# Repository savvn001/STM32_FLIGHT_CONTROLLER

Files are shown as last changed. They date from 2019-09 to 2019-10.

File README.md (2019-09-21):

# STM32_FLIGHT_CONTROLLER

(Still undergoing active development)

Open source flight controller running on an STM32F411RE MCU and a custom designed PCB. Project written in STM32cubeIDE. 

The other modules this flight controller currently uses:

- NRF24L01PA for RF comms
- GPS is provided by a uBlox NEO6M GPS module
- Orientation from an MPU9250 9-axis IMU.

Current features:
- User control
- Packetised RF communications
- GPS 
- In flight monitoring of telemetry information (battery level, orientation, GPS co-ordinates etc.)
- More to come!

The first revision of the flight controller designed in eagle is shown below.

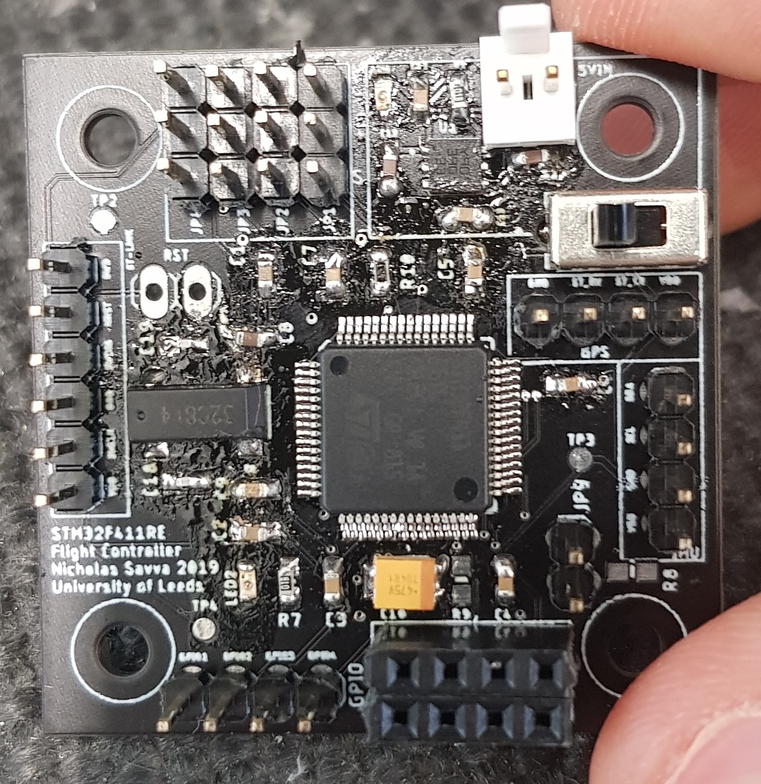
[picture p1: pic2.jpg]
Flight controller PCB


The controller features headers for I2C, 4 GPIO pins, UART and an NRF24L01 module. The code for the associated user controller/transmitter is here: https://github.com/savvn001/DRONE_CONTROLLER_F4746NG

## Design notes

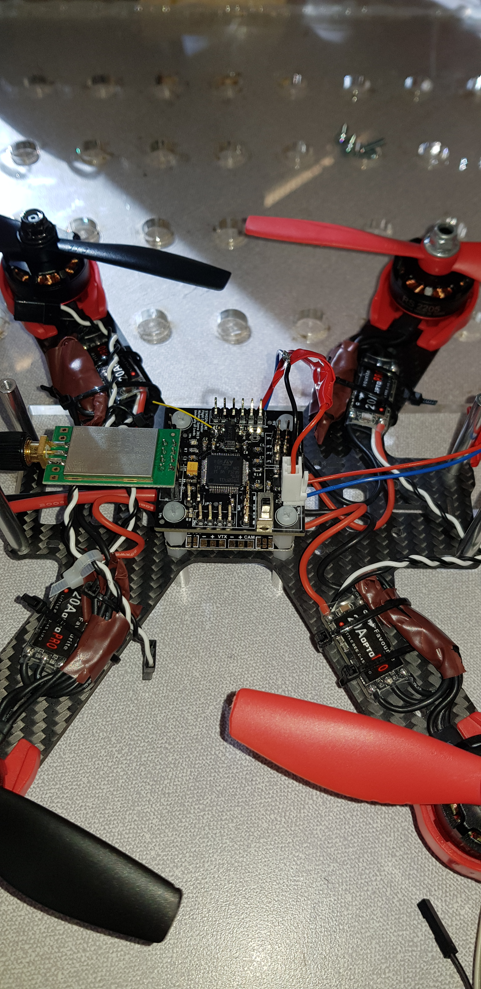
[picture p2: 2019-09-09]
pic1.jpg

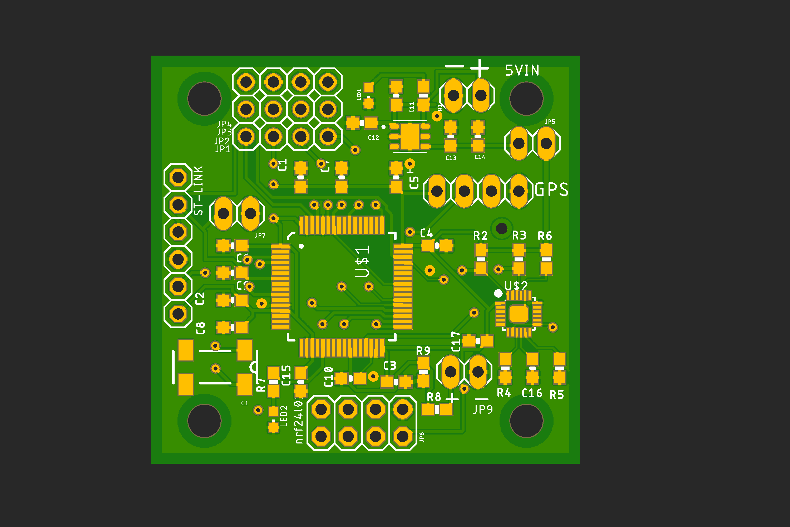
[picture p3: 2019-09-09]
STM32F411RE_Flight_Controller_Eagle/Flight_Controller_board.png

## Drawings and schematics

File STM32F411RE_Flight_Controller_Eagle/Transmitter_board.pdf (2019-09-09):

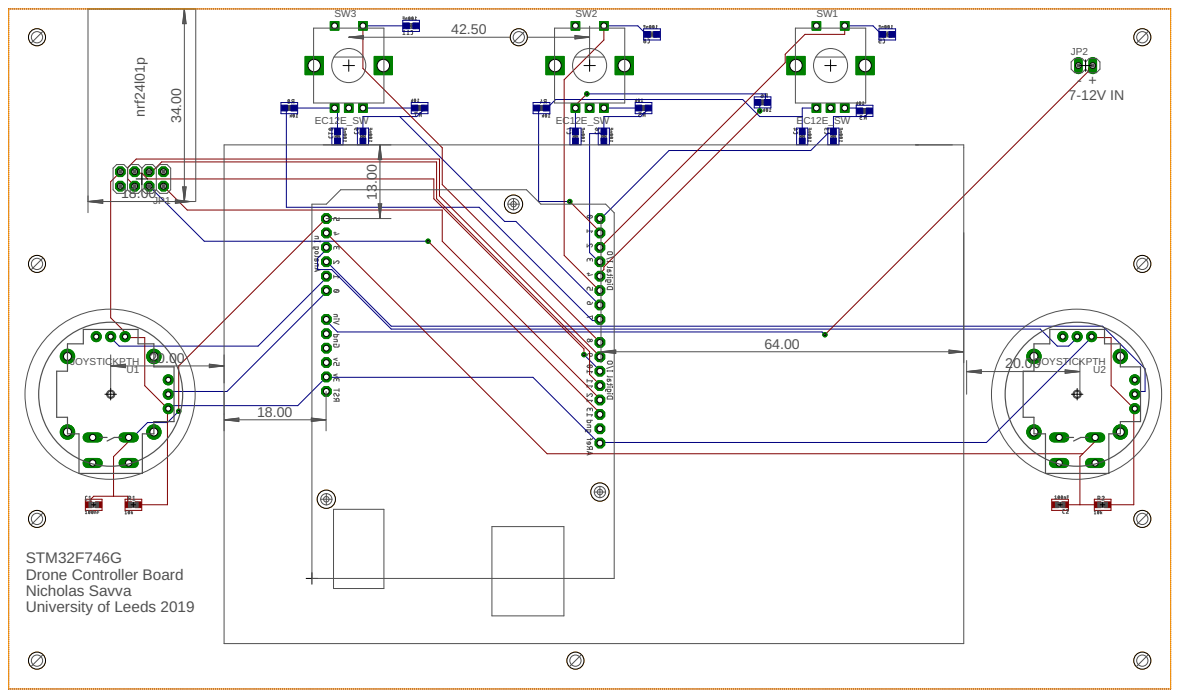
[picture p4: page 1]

STM32F746G
Drone Controller Board
Nicholas Savva University of Leeds 2019

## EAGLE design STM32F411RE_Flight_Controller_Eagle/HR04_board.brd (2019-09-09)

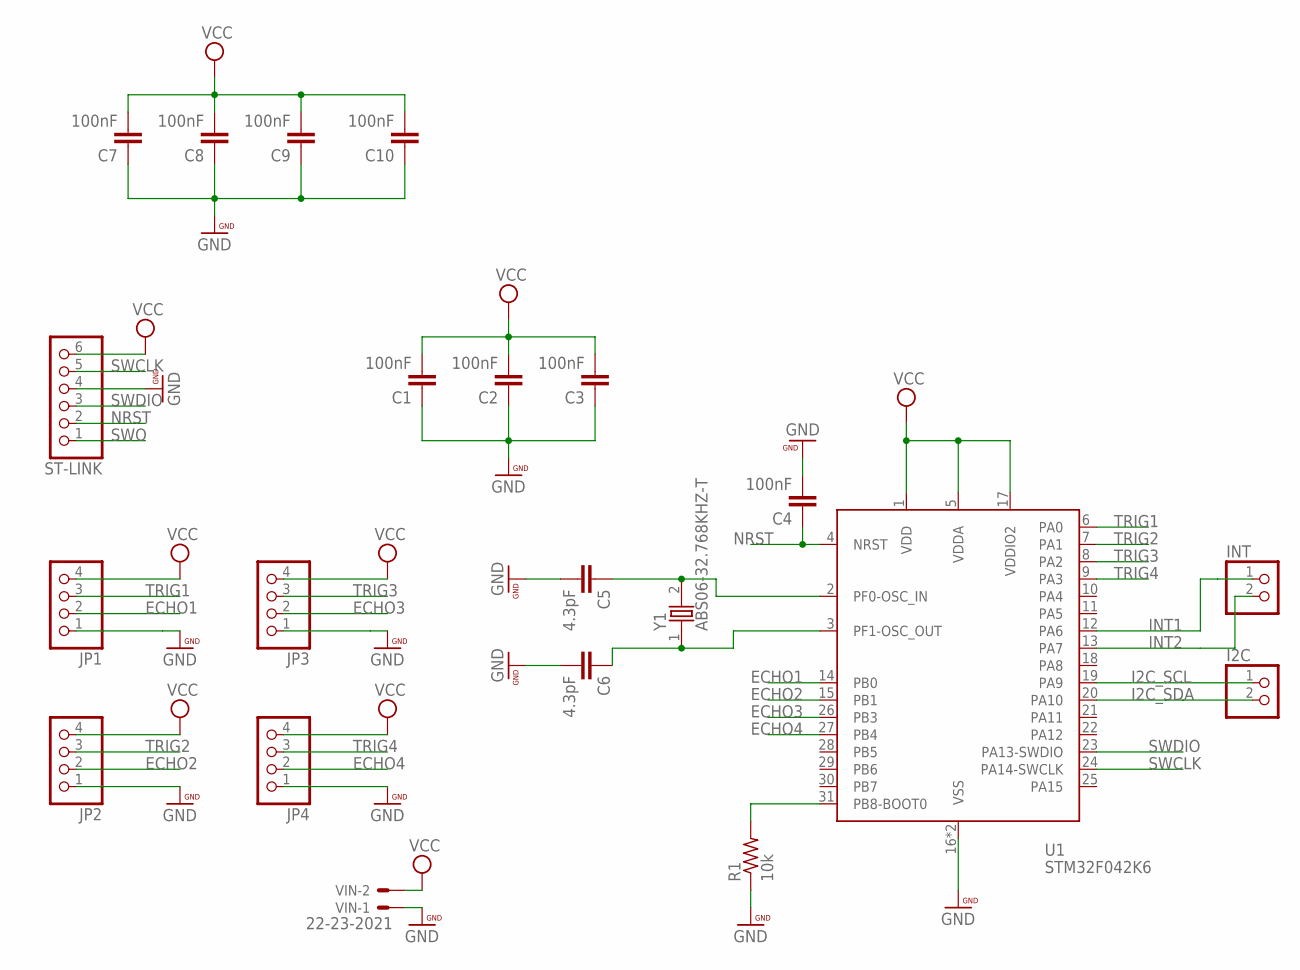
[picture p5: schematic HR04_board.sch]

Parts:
C1, C2, C3, C4, C7, C8, C9, C10: 100nF; 0603-CAP
C5, C6: 4.3pF; 0402-CAP
I2C: PINHD-1X2; 1X02
INT: PINHD-1X2; 1X02
JP1, JP2, JP3, JP4: PINHD-1X4; 1X04
R1: 10k; R0603
ST-LINK: PINHD-1X6; 1X06
U1: STM32F042K6; QFP32-7X7
VIN: 22-23-2021
Y1: ABS06-32.768KHZ-T; XTAL_ABS06-32.768KHZ-T

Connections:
ECHO1: JP1.2, U1.14 (PB0)
ECHO2: JP2.2, U1.15 (PB1)
ECHO3: JP3.2, U1.26 (PB3)
ECHO4: JP4.2, U1.27 (PB4)
GND: C1.1, C2.1, C3.1, C4.2, C5.2, C6.2, C7.1, C8.1, C9.1, C10.1, JP1.1, JP2.1, JP3.1, JP4.1, R1.1, ST-LINK.4, U1.16 (VSS), U1.32 (VSS), VIN.1
I2C_SCL: I2C.1, U1.19 (PA9)
I2C_SDA: I2C.2, U1.20 (PA10)
INT1: INT.1, U1.12 (PA6)
INT2: INT.2, U1.13 (PA7)
unnamed: R1.2, U1.31 (PB8-BOOT0)
unnamed: C5.1, U1.2 (PF0-OSC_IN), Y1.2
unnamed: C6.1, U1.3 (PF1-OSC_OUT), Y1.1
NRST: C4.1, ST-LINK.2, U1.4 (NRST)
SWCLK: ST-LINK.5, U1.24 (PA14-SWCLK)
SWDIO: ST-LINK.3, U1.23 (PA13-SWDIO)
SWO: ST-LINK.1
TRIG1: JP1.3, U1.6 (PA0)
TRIG2: JP2.3, U1.7 (PA1)
TRIG3: JP3.3, U1.8 (PA2)
TRIG4: JP4.3, U1.9 (PA3)
VCC: C1.2, C2.2, C3.2, C7.2, C8.2, C9.2, C10.2, JP1.4, JP2.4, JP3.4, JP4.4, ST-LINK.6, U1.1 (VDD), U1.5 (VDDA), U1.17 (VDDIO2), VIN.2

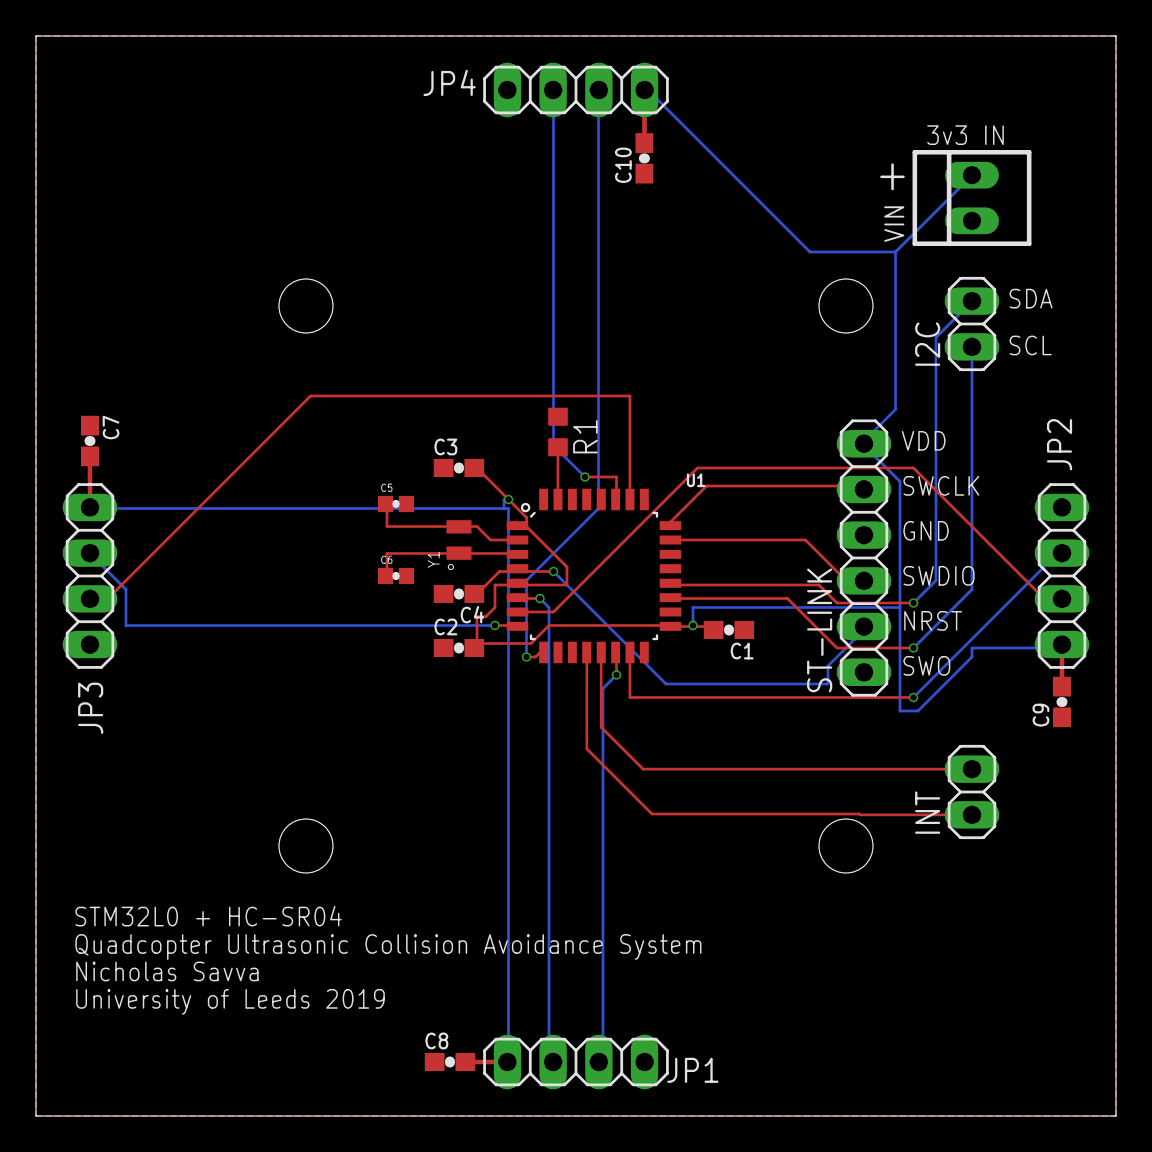
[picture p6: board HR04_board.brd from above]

Board: 2 copper layers, 60.0 x 60.0 mm, 21 parts (0 on the bottom side), 20 nets.

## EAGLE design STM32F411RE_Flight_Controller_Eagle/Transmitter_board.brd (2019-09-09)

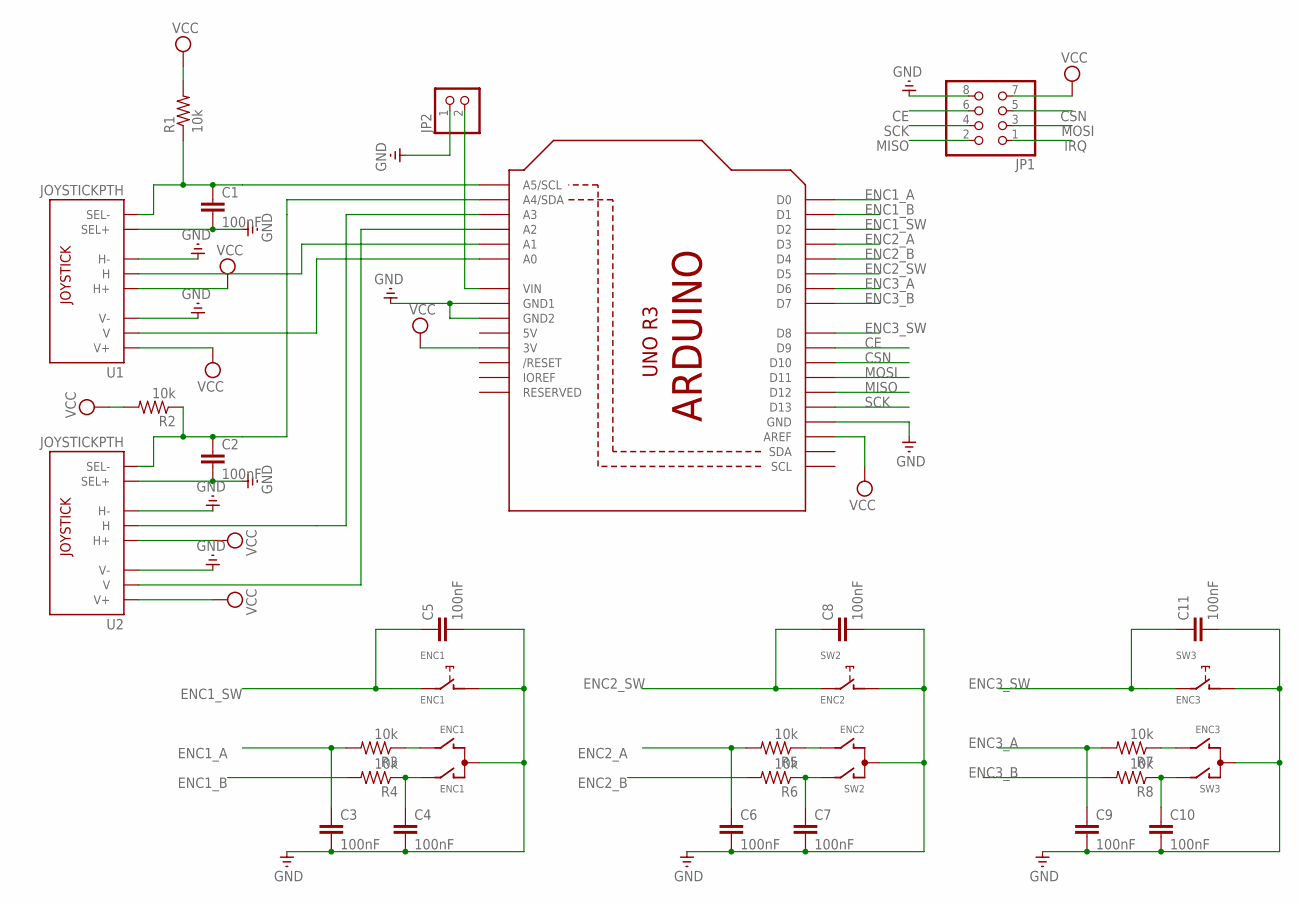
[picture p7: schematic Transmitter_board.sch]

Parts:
C1, C2, C3, C4, C5, C6, C7, C8, C9, C10, C11: 100nF; 0603-CAP
ENC1: ENC1; ALPS_EC12E_SW
JP1: PINHD-2X4; 2X04
JP2: PINHD-1X2; 1X02
R1, R2, R3, R4, R5, R6, R7, R8: 10k; 0603-RES
SW2: ENC2; ALPS_EC12E_SW
SW3: ENC3; ALPS_EC12E_SW
U1, U2: JOYSTICKPTH; JOYSTICK
U3: STM32F746NG; ARDUINOR3-BPLACE

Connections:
5V: U3.5V
CE: JP1.6, U3.D9
CSN: JP1.5, U3.D10
ENC1_A: C3.1, R3.2, U3.D0
ENC1_B: R4.2, U3.D1
ENC1_SW: C5.1, ENC1.E (2), U3.D2
ENC2_A: C6.1, R5.2, U3.D3
ENC2_B: R6.2, U3.D4
ENC2_SW: C8.1, SW2.E (2), U3.D5
ENC3_A: C9.1, R7.2, U3.D6
ENC3_B: R8.2, U3.D7
ENC3_SW: C11.1, SW3.E (2), U3.D8
GND: C1.2, C2.2, C3.2, C4.2, C5.2, C6.2, C7.2, C8.2, C9.2, C10.2, C11.2, ENC1.C, ENC1.D (1), JP1.8, JP2.1, SW2.C, SW2.D (1), SW3.C, SW3.D (1), U1.B1A (SEL+), U1.H3 (H-), U1.V3 (V-), U2.B1A (SEL+), U2.H3 (H-), U2.V3 (V-), U3.GND, U3.GND1, U3.GND2
IRQ: JP1.1
MISO: JP1.2, U3.D12
MOSI: JP1.3, U3.D11
unnamed: U2.V2 (V), U3.A2
unnamed: C2.1, R2.1, U2.B2A (SEL-), U3.A4 (A4/SDA)
unnamed: JP2.2, U3.VIN
unnamed: C1.1, R1.1, U1.B2A (SEL-), U3.A5 (A5/SCL)
unnamed: C4.1, ENC1.A, R4.1
unnamed: C7.1, R6.1, SW2.A
unnamed: ENC1.B, R3.1
unnamed: R5.1, SW2.B
unnamed: C10.1, R8.1, SW3.A
unnamed: R7.1, SW3.B
unnamed: U1.H2 (H), U3.A1
unnamed: U1.V2 (V), U3.A0
unnamed: U2.H2 (H), U3.A3
SCK: JP1.4, U3.D13
VCC: JP1.7, R1.2, R2.2, U1.H1 (H+), U1.V1 (V+), U2.H1 (H+), U2.V1 (V+), U3.3V, U3.AREF

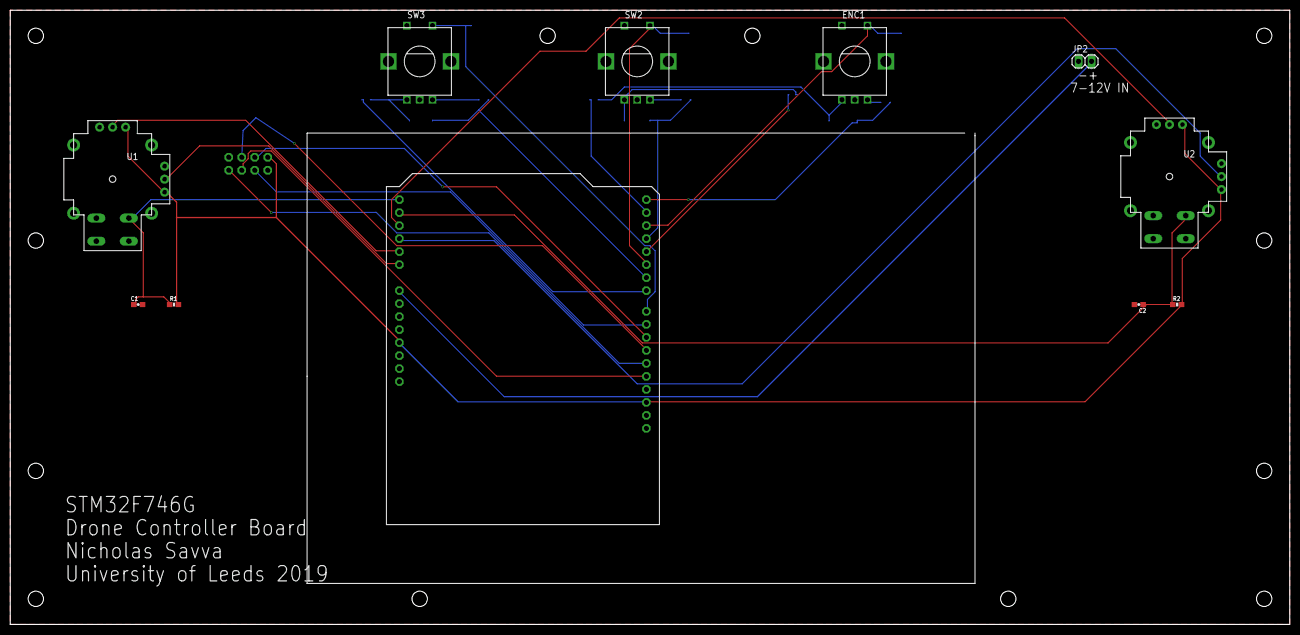
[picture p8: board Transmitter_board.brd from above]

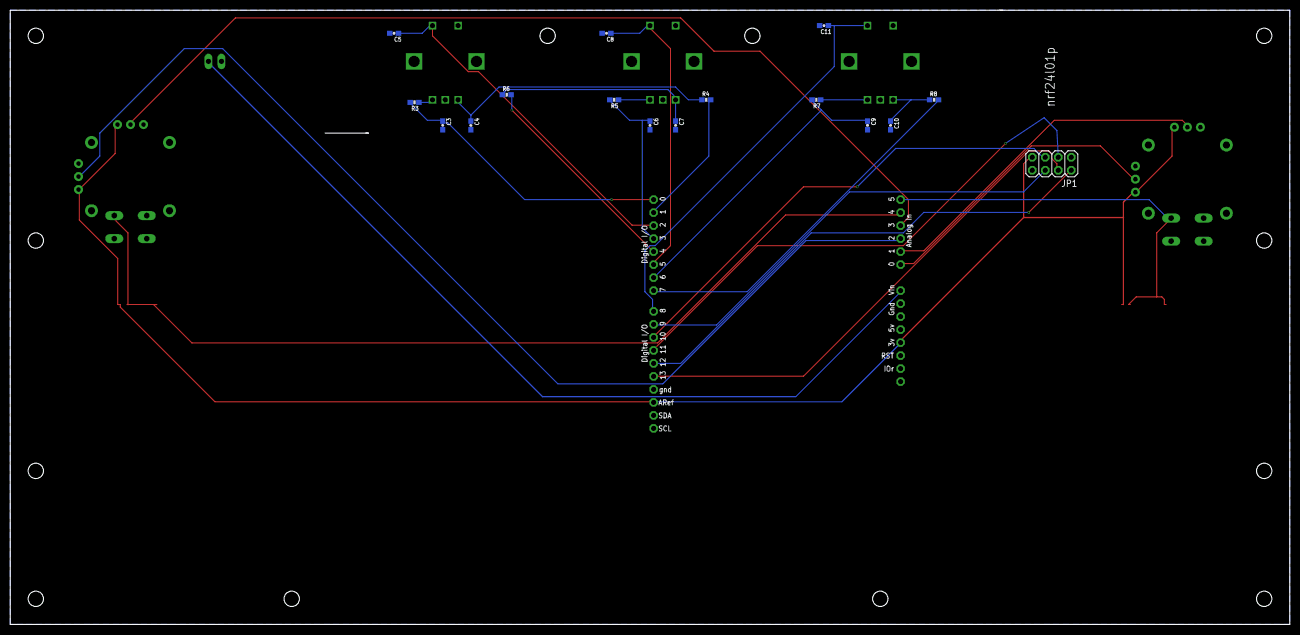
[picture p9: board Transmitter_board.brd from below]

Board: 2 copper layers, 250.0 x 120.0 mm, 27 parts (17 on the bottom side), 29 nets.

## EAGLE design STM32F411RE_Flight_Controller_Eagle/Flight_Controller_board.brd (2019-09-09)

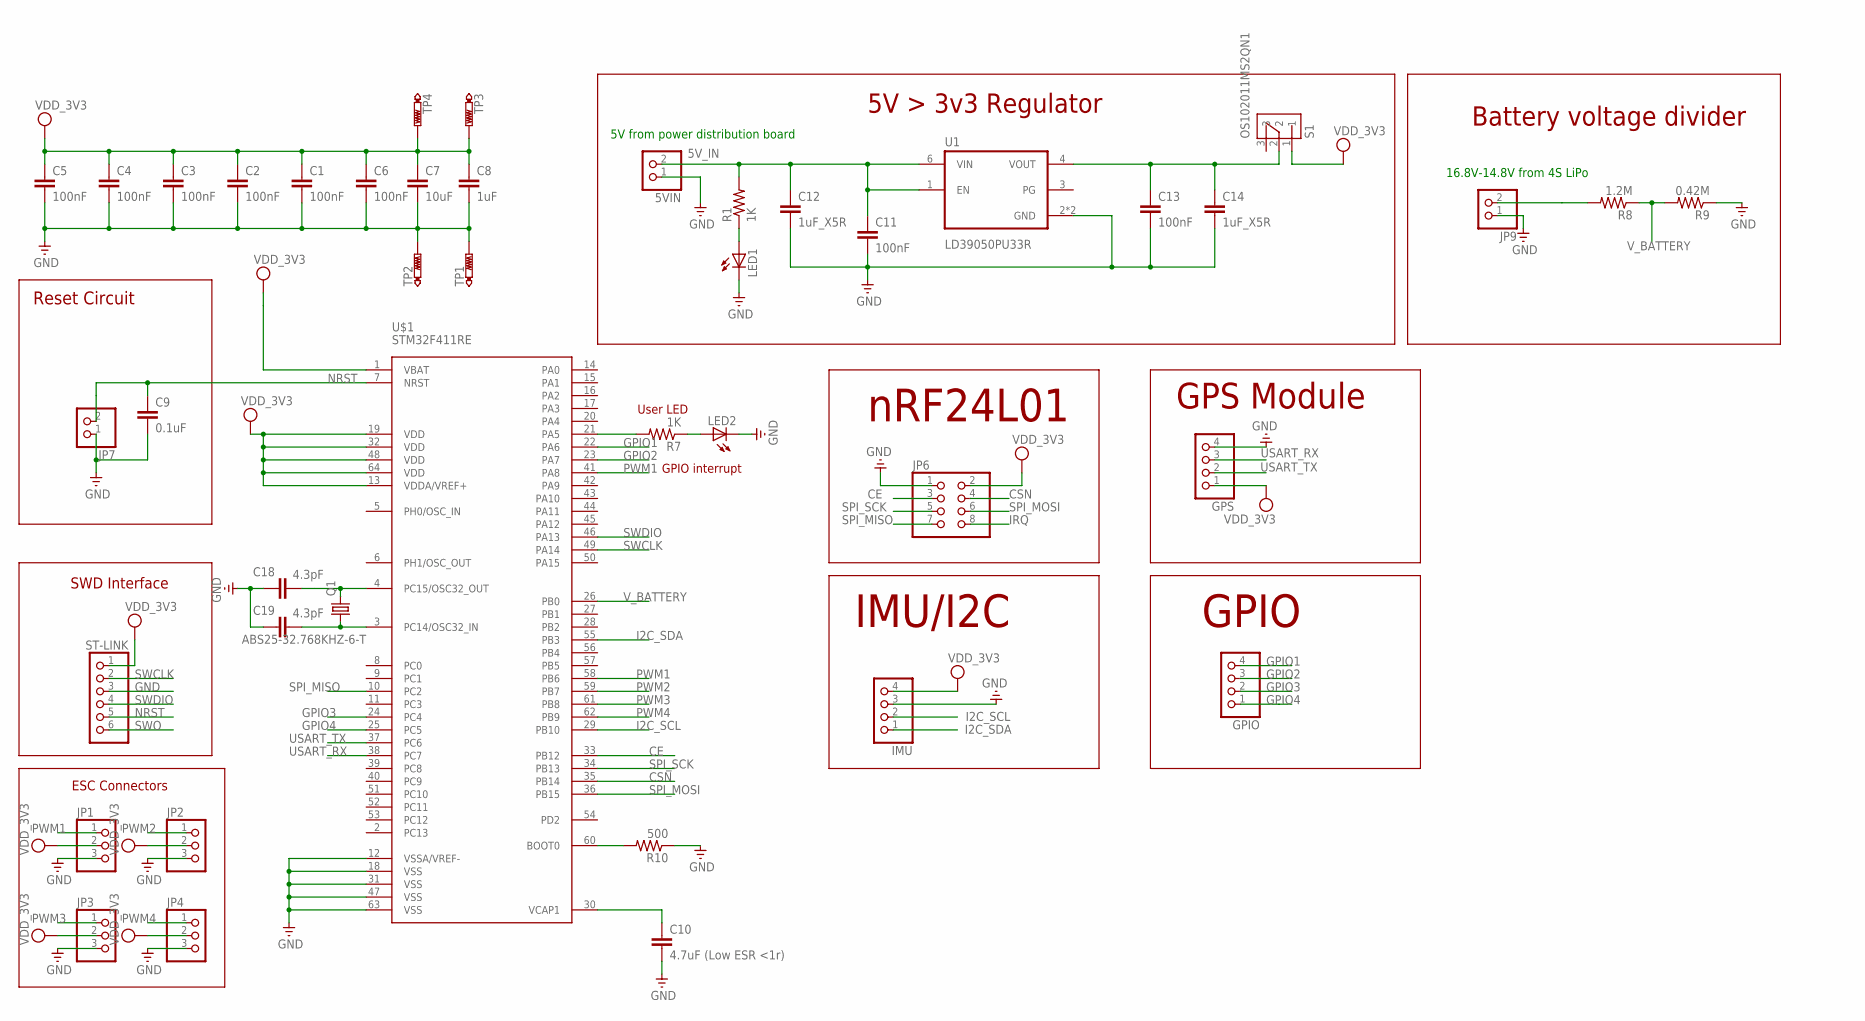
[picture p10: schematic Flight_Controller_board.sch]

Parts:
5VIN: PINHD-1X2; 1X02
C1, C2, C3, C4, C5, C6, C11, C13: 100nF; 0603-CAP
C7: 10uF; 0603-CAP
C8: 1uF; 0603-CAP
C9: 0.1uF; 0603-CAP
C10: 4.7uF (Low ESR <1r); 1210
C12, C14: 1uF_X5R; 0603-CAP
C18, C19: 4.3pF; 0603-CAP
GPIO: PINHD-1X4; 1X04
GPS: PINHD-1X4; 1X04
IMU: PINHD-1X4; 1X04
JP1, JP2, JP3, JP4: PINHD-1X3; 1X03
JP6: PINHD-2X4; 2X04
JP7, JP9: PINHD-1X2; 1X02
LED1, LED2: LEDCHIPLED_0603; CHIPLED_0603
Q1: ABS25-32.768KHZ-6-T; MC-306
R1, R7: 1K; 0603-RES
R8: 1.2M; 0603-RES
R9: 0.42M; 0603-RES
R10: 500; 0603-RES
S1: OS102011MS2QN1; SW_OS102011MS2QN1
ST-LINK: PINHD-1X6; 1X06
TP1, TP2, TP3, TP4: PTR1B1,27; B1,27
U1: LD39050PU33R; SON95P300X300X100-7N
U$1: STM32F411RE; LQFP64

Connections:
5V_IN: 5VIN.2, C11.1, C12.1, R1.2, U1.1 (EN), U1.6 (VIN)
CE: JP6.3, U$1.33 (PB12)
CSN: JP6.4, U$1.35 (PB14)
GND: 5VIN.1, C1.2, C2.2, C3.2, C4.2, C5.2, C6.2, C7.2, C8.2, C9.2, C10.2, C11.2, C12.2, C13.2, C14.2, C18.1, C19.1, GPS.4, IMU.3, JP1.3, JP2.3, JP3.3, JP4.3, JP6.1, JP7.1, JP9.1, LED1.C, LED2.C, R9.1, R10.1, ST-LINK.3, TP1.TP, TP2.TP, U1.2 (GND), U1.7 (GND), U$1.12 (VSSA/VREF-), U$1.18 (VSS), U$1.31 (VSS), U$1.47 (VSS), U$1.63 (VSS)
GPIO1: GPIO.4, U$1.22 (PA6)
GPIO2: GPIO.3, U$1.23 (PA7)
GPIO3: GPIO.2, U$1.24 (PC4)
GPIO4: GPIO.1, U$1.25 (PC5)
I2C_SCL: IMU.2, U$1.29 (PB10)
I2C_SDA: IMU.1, U$1.55 (PB3)
IRQ: JP6.8
unnamed: C10.1, U$1.30 (VCAP1)
unnamed: C13.1, C14.1, S1.2, U1.4 (VOUT)
unnamed: R7.2, U$1.21 (PA5)
unnamed: LED1.A, R1.1
unnamed: LED2.A, R7.1
unnamed: C18.2, Q1.4 (2), U$1.4 (PC15/OSC32_OUT)
unnamed: C19.2, Q1.1, U$1.3 (PC14/OSC32_IN)
unnamed: JP9.2, R8.2
unnamed: R10.2, U$1.60 (BOOT0)
NRST: C9.1, JP7.2, ST-LINK.5, U$1.7 (NRST)
PWM1: JP1.1, U$1.41 (PA8), U$1.58 (PB6)
PWM2: JP2.1, U$1.59 (PB7)
PWM3: JP3.1, U$1.61 (PB8)
PWM4: JP4.1, U$1.62 (PB9)
SPI_MISO: JP6.7, U$1.10 (PC2)
SPI_MOSI: JP6.6, U$1.36 (PB15)
SPI_SCK: JP6.5, U$1.34 (PB13)
SWCLK: ST-LINK.2, U$1.49 (PA14)
SWDIO: ST-LINK.4, U$1.46 (PA13)
SWO: ST-LINK.6
USART_RX: GPS.3, U$1.38 (PC7)
USART_TX: GPS.2, U$1.37 (PC6)
VDD: C1.1, C2.1, C3.1, C4.1, C5.1, C6.1, C7.1, C8.1, GPS.1, IMU.4, JP1.2, JP2.2, JP3.2, JP4.2, JP6.2, S1.1, ST-LINK.1, TP3.TP, TP4.TP, U$1.1 (VBAT), U$1.13 (VDDA/VREF+), U$1.19 (VDD), U$1.32 (VDD), U$1.48 (VDD), U$1.64 (VDD)
V_BATTERY: R8.1, R9.2, U$1.26 (PB0)

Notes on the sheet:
Reset Circuit
SWD Interface
ESC Connectors
5V > 3v3 Regulator
nRF24L01
GPS Module
16.8V-14.8V from 4S LiPo
Battery voltage divider
GPIO interrupt
User LED
5V from power distribution board
IMU/I2C
GPIO

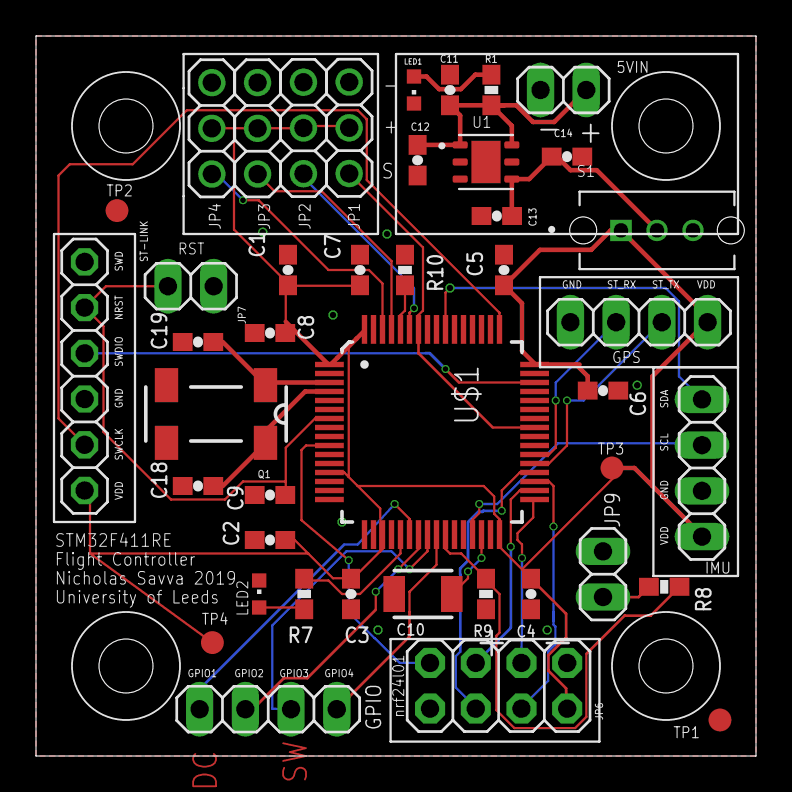
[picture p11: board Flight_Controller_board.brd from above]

Board: 2 copper layers, 40.0 x 40.0 mm, 43 parts (0 on the bottom side), 33 nets.

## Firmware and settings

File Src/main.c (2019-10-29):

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

/* Includes ------------------------------------------------------------------*/
#include "main.h"
#include "cmsis_os.h"
#include "crc.h"
#include "i2c.h"
#include "spi.h"
#include "tim.h"
#include "usart.h"
#include "gpio.h"


void SystemClock_Config(void);
void MX_FREERTOS_Init(void);
/* USER CODE BEGIN PFP */

void ARM_ESCs();


void pulse_posedge_handler();

void print_data_to_pc();
void update_PID_values();


int __io_putchar(int ch);
int _write(int file, char *ptr, int len);

void HAL_GPIO_EXTI_Callback(uint16_t GPIO_Pin);
void HAL_TIM_IC_CaptureCallback(TIM_HandleTypeDef *htim);
void HAL_TIM_PeriodElapsedCallback(TIM_HandleTypeDef *htim);
void printToPC();


unsigned int new_conversion_processing(unsigned int new_data);

/* USER CODE END PFP */

/**
  * @brief  The application entry point.
  * @retval int
  */
int main(void)
{
  

  /* MCU Configuration--------------------------------------------------------*/

  /* Reset of all peripherals, Initializes the Flash interface and the Systick. */
  HAL_Init();

  /* Configure the system clock */
  SystemClock_Config();

  /* Initialize all configured peripherals */
  MX_GPIO_Init();
  MX_I2C2_Init();
  MX_TIM4_Init();
  MX_SPI2_Init();
  MX_CRC_Init();
  MX_TIM11_Init();
  MX_USART6_UART_Init();
  MX_TIM10_Init();
  /* USER CODE BEGIN 2 */


	/////////////////////////////////////////////////////////////////
	/////////////////////////////// GPS /////////////////////////////
	/////////////////////////////////////////////////////////////////

  //vTraceEnable(TRC_INIT);


  /* USER CODE END 2 */

  /* Call init function for freertos objects (in freertos.c) */
  MX_FREERTOS_Init(); 

  /* Start scheduler */
  osKernelStart();
  
  /* We should never get here as control is now taken by the scheduler */

  /* Infinite loop */
  /* USER CODE BEGIN WHILE */
	while (1) {

//		}

    /* USER CODE END WHILE */

    /* USER CODE BEGIN 3 */
	}
  /* USER CODE END 3 */
}

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
/* USER CODE BEGIN 4 */

//void ARM_ESCs() {
//
//	HAL_Delay(2000); //Wait
//
//	int delay_time = 8000;
//
//	PWM1_Set(ESC_MAX); //Send max value (250us pulse)
//	PWM2_Set(ESC_MAX); //Send max value (250us pulse)
//	PWM3_Set(ESC_MAX); //Send max value (250us pulse)
//	PWM4_Set(ESC_MAX); //Send max value (250us pulse)
//
//	//Try setting a breakpoint here and switching on PWR supply here??
//	//ESC needs a high signal switched on
//
//	HAL_Delay(delay_time); //Wait
//
//	PWM1_Set(ESC_MIN); //Send lowest value (125us pulse)
//	PWM2_Set(ESC_MIN); //Send lowest value (125us pulse)
//	PWM3_Set(ESC_MIN); //Send lowest value (125us pulse)
//	PWM4_Set(ESC_MIN); //Send lowest value (125us pulse)
//
//	HAL_Delay(delay_time); //Wait
//
//}


int divider = 0;



#if BATTERY
void HAL_ADC_ConvCpltCallback(ADC_HandleTypeDef* hadc) {

	batteryLevel = HAL_ADC_GetValue(&hadc1);

	//Simple exponential moving average filter where alpha = 2/(N+1)

	float alpha = 0.10;
	avgBatteryLevel = alpha * batteryLevel + (1 - alpha) * lastAvgBatteryLevel;
	lastAvgBatteryLevel = avgBatteryLevel;

	if (N > 20) {
		//Shut off PWM when battery level too low
		if (avgBatteryLevel < ADC_BATTERY_SHUTOFF) {
			kill();
		}
	} else {
		N++;
	}
}

#endif
/* USER CODE END 4 */

/**
  * @brief  Period elapsed callback in non blocking mode
  * @note   This function is called  when TIM1 interrupt took place, inside
  * HAL_TIM_IRQHandler(). It makes a direct call to HAL_IncTick() to increment
  * a global variable "uwTick" used as application time base.
  * @param  htim : TIM handle
  * @retval None
  */
void HAL_TIM_PeriodElapsedCallback(TIM_HandleTypeDef *htim)
{
  if (htim->Instance == TIM1) {
    HAL_IncTick();
  }
}

/**
  * @brief  This function is executed in case of error occurrence.
  * @retval None
  */
void Error_Handler(void)
{
  /* USER CODE BEGIN Error_Handler_Debug */
	/* User can add his own implementation to report the HAL error return state */

  /* USER CODE END Error_Handler_Debug */
}

#ifdef  USE_FULL_ASSERT
/**
  * @brief  Reports the name of the source file and the source line number
  *         where the assert_param error has occurred.
  * @param  file: pointer to the source file name
  * @param  line: assert_param error line source number
  * @retval None
  */
void assert_failed(uint8_t *file, uint32_t line)
{ 
  /* USER CODE BEGIN 6 */
	/* User can add his own implementation to report the file name and line number,
     tex: printf("Wrong parameters value: file %s on line %d\r\n", file, line) */
  /* USER CODE END 6 */
}
#endif /* USE_FULL_ASSERT */

/************************ (C) COPYRIGHT STMicroelectronics *****END OF FILE****/

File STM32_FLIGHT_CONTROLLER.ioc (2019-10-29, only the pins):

Mcu.UserName=STM32F411RETx
PA13.Signal=SYS_JTMS-SWDIO
PA14.Signal=SYS_JTCK-SWCLK
PA5.Signal=GPIO_Output
PA8.GPIO_Label=PWM_INT
PA8.Signal=GPXTI8
PB10.Signal=I2C2_SCL
PB12.Signal=GPIO_Output
PB13.Signal=SPI2_SCK
PB14.Signal=GPIO_Output
PB15.Signal=SPI2_MOSI
PB3.Signal=I2C2_SDA
PB6.Signal=S_TIM4_CH1
PB7.Signal=S_TIM4_CH2
PB8.Signal=S_TIM4_CH3
PB9.Signal=S_TIM4_CH4
PC2.Signal=SPI2_MISO
PC5.Signal=GPIO_Output
PC6.Signal=USART6_TX
PC7.Signal=USART6_RX

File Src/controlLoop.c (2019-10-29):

#include "controlLoop.h"

#include "../Drivers/PID.h"
#include <stdbool.h>
#include <stdio.h>
#include "arm_math.h"
#include "i2c.h"
#include "tim.h"
#include "../Drivers/IMU.h"


#define IMU 1
//1 if motors to be used
#define MOTORS 1

//////////////////////////////////// IMU variables /////////////////////////

//IMU roll, pitch & yaw angles in degrees
float imu_roll = 0;
float imu_pitch = 0;
float imu_yaw = 0;
//This holds the rotation rate of the yaw axis in °/sec
float imu_yaw_rate = 0;

//////////////////////////////////// PID variables /////////////////////////
int roll_setpoint = 0;
int pitch_setpoint = 0;
float yaw_setpoint = 0;
float pid_output_roll = 0;
float pid_output_pitch = 0;
float pid_output_yaw = 0;

int tim11_count = 0;

int N = 0;

uint16_t throttle = 0;

int esc1_total = 0;
int esc2_total = 0;
int esc3_total = 0;
int esc4_total = 0;

bool getRPY_flag = 0;

float ax, ay, az;
float gx, gy, gz;
float mx, my, mz;
float temp;





void CL_init() {
#if IMU

	//Start timer 11, used for integral calculations
	HAL_TIM_Base_Start(&htim11);

	if (imu_init(&hi2c2) == IMU_SUCCESS) {
		imu_calibrate();
	}

#endif

	/////////////////////////////////////////////////////////////////
	////////////////////////// Init timers for PWM //////////////////
	/////////////////////////////////////////////////////////////////

	//Start up PWMs
	HAL_TIM_PWM_Start(&htim4, TIM_CHANNEL_1);
	HAL_TIM_PWM_Start(&htim4, TIM_CHANNEL_2);
	HAL_TIM_PWM_Start(&htim4, TIM_CHANNEL_3);
	HAL_TIM_PWM_Start(&htim4, TIM_CHANNEL_4);

	//ARM_ESCs(); //Force arming sequence

//	PWM1_Set(2500);
//	PWM2_Set(2500);
//	PWM3_Set(2500);
//	PWM4_Set(2500);

}


uint16_t yaw_ctr = 0;
bool done = 0;
/* ------------------------------ MAIN CONTROL LOOP --------------------------------------
 *
 * Calculate the required pulse widths to set individual motor speeds based off of IMU
 * readings and instructions from controller.
 *
 * For the QAV210 kit the orientation is as so:
 *
 * 	    (Front)
 *
 * (2 CCW)    (4 CW)
 *		\	  /
 *		   |
 *		   |
 *		   |
 *		/     \
 * (1 CW)     (3 CCW)
 *
 */
void CL_main(bool airmode, uint16_t throttle, float pitch_setpoint, float roll_setpoint, float yaw_setpoint, float *roll, float *pitch, float *yaw ) {




#if IMU

	calc_RollPitchYaw(roll, pitch, NULL, yaw);


#endif
	if (airmode && throttle > 1250) {
		/*******    Pitch PID calculation  ********/
		pid_output_pitch = pid_calculate_pitch(imu_pitch, 0, pitch_setpoint);

		/*******    Roll PID calculation  ********/

		pid_output_roll = pid_calculate_roll(imu_roll, 0, roll_setpoint);

		/*******    Yaw PID calculation  ********/

		pid_output_yaw = pid_calculate_yaw(imu_yaw_rate, 0, yaw_setpoint);
	} else {
		pid_output_roll = 0;
		pid_output_pitch = 0;
		pid_output_yaw = 0;
		reset_pid_roll();
		reset_pid_pitch();
		reset_pid_yaw();
	}

	/*** For tuning PID, store in buffer to print to PC later ***/
#if PID_TUNE_DEBUG
		if (print_buffer_index < SAMPLES) {
			PID_print_buffer[print_buffer_index] = roll;
			IMU_print_buffer[print_buffer_index] = roll;

			print_buffer_index++;
		} else {
			printToPC();
		}
#endif

	//Calculate new pulse width values
	esc1_total = throttle + (int) pid_output_roll + (int) pid_output_pitch + (int) pid_output_yaw;
	esc2_total = throttle + (int) pid_output_roll - (int) pid_output_pitch - (int) pid_output_yaw;
	esc3_total = throttle - (int) pid_output_roll + (int) pid_output_pitch - (int) pid_output_yaw;
	esc4_total = throttle - (int) pid_output_roll - (int) pid_output_pitch + (int) pid_output_yaw;

	//Clip PWM values to make sure they don't go outside of range
	if (esc1_total < ESC_MIN) {
		esc1_total = ESC_MIN;
	}
	if (esc1_total > ESC_MAX) {
		esc1_total = ESC_MAX;
	}
	if (esc2_total < ESC_MIN) {
		esc2_total = ESC_MIN;
	}
	if (esc2_total > ESC_MAX) {
		esc2_total = ESC_MAX;
	}
	if (esc3_total < ESC_MIN) {
		esc3_total = ESC_MIN;
	}
	if (esc3_total > ESC_MAX) {
		esc3_total = ESC_MAX;
	}
	if (esc4_total < ESC_MIN) {
		esc4_total = ESC_MIN;
	}
	if (esc4_total > ESC_MAX) {
		esc4_total = ESC_MAX;
	}
#if MOTORS
		//Load new pulse widths into ESCs
		PWM1_Set(esc1_total); //PWM1 = Back left, CW
		PWM2_Set(esc2_total); //PWM2 = Front left, CCW
		PWM3_Set(esc3_total); //PWM3 = Back right, CCW
		PWM4_Set(esc4_total); //PWM4 = Front right, CW

#endif

		HAL_GPIO_TogglePin(GPIOC, GPIO_PIN_5);


}



/*
 *  In case connection to transmitter is lost, slowly power down motors
 *  in order to gently lower quadcopter as opposed to suddenly shutting them off
 *
 */
void lostConnection() {

	/*
	//Force airmode
	Rx_Data.airmode = 1;

	//Reset joystick positions to centre
	roll_setpoint = 0;
	pitch_setpoint = 0;

	//Decrease throttle down to min value
	if (throttle > ESC_MIN) {
		throttle--;
		NRF24_DelayMicroSeconds(5000);
	} else {
		//Then turn off motors fully to be sure
		kill();
	}
*/
}

/*
 * Reset NRF24 module
 */
void resetNRF24() {

//	NRF24_powerDown();
//	DWT_Init(); //Enable some of the MCUs special registers so we can get microsecond (us) delays
//	NRF24_begin(GPIOB, nrf_CSN_PIN, nrf_CE_PIN, hspi2);
//	//nrf24_DebugUART_Init(huart2);
//	NRF24_setAutoAck(true);
//	NRF24_enableAckPayload();
//	NRF24_openReadingPipe(1, TxpipeAddrs);
//	NRF24_startListening();

}

//These 4 functions set the PWM duty cycles
void PWM1_Set(uint16_t value) {
	htim4.Instance->CCR1 = value;
}

void PWM2_Set(uint16_t value) {
	htim4.Instance->CCR2 = value;

}

void PWM3_Set(uint16_t value) {
	htim4.Instance->CCR3 = value;
}

void PWM4_Set(uint16_t value) {
	htim4.Instance->CCR4 = value;
}

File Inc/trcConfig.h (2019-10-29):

/*******************************************************************************
 * Trace Recorder Library for Tracealyzer v4.3.5
 * Percepio AB, www.percepio.com
 *
 * trcConfig.h
 *
 * Main configuration parameters for the trace recorder library.
 * More settings can be found in trcStreamingConfig.h and trcSnapshotConfig.h.
 *
 * Read more at http://percepio.com/2016/10/05/rtos-tracing/
 *
 * Terms of Use
 * This file is part of the trace recorder library (RECORDER), which is the
 * intellectual property of Percepio AB (PERCEPIO) and provided under a
 * license as follows.
 * The RECORDER may be used free of charge for the purpose of recording data
 * intended for analysis in PERCEPIO products. It may not be used or modified
 * for other purposes without explicit permission from PERCEPIO.
 * You may distribute the RECORDER in its original source code form, assuming
 * this text (terms of use, disclaimer, copyright notice) is unchanged. You are
 * allowed to distribute the RECORDER with minor modifications intended for
 * configuration or porting of the RECORDER, e.g., to allow using it on a
 * specific processor, processor family or with a specific communication
 * interface. Any such modifications should be documented directly below
 * this comment block.
 *
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
 * Tabs are used for indent in this file (1 tab = 4 spaces)
 *
 * Copyright Percepio AB, 2018.
 * www.percepio.com
 ******************************************************************************/

#ifndef TRC_CONFIG_H
#define TRC_CONFIG_H

#ifdef __cplusplus
extern "C" {
#endif

#include "trcPortDefines.h"

/******************************************************************************
 * Include of processor header file
 *
 * Here you may need to include the header file for your processor. This is
 * required at least for the ARM Cortex-M port, that uses the ARM CMSIS API.
 * Try that in case of build problems. Otherwise, remove the #error line below.
 *****************************************************************************/
//#error "Trace Recorder: Please include your processor's header file here and remove this line."

#include "stm32f4xx.h"

/*******************************************************************************
 * Configuration Macro: TRC_CFG_HARDWARE_PORT
 *
 * Specify what hardware port to use (i.e., the "timestamping driver").
 *
 * All ARM Cortex-M MCUs are supported by "TRC_HARDWARE_PORT_ARM_Cortex_M".
 * This port uses the DWT cycle counter for Cortex-M3/M4/M7 devices, which is
 * available on most such devices. In case your device don't have DWT support,
 * you will get an error message opening the trace. In that case, you may
 * force the recorder to use SysTick timestamping instead, using this define:
 *
 * #define TRC_CFG_ARM_CM_USE_SYSTICK
 *
 * For ARM Cortex-M0/M0+ devices, SysTick mode is used automatically.
 *
 * See trcHardwarePort.h for available ports and information on how to
 * define your own port, if not already present.
 ******************************************************************************/
#define TRC_CFG_HARDWARE_PORT TRC_HARDWARE_PORT_ARM_Cortex_M

/*******************************************************************************
 * Configuration Macro: TRC_CFG_RECORDER_MODE
 *
 * Specify what recording mode to use. Snapshot means that the data is saved in
 * an internal RAM buffer, for later upload. Streaming means that the data is
 * transferred continuously to the host PC.
 *
 * For more information, see http://percepio.com/2016/10/05/rtos-tracing/
 * and the Tracealyzer User Manual.
 *
 * Values:
 * TRC_RECORDER_MODE_SNAPSHOT
 * TRC_RECORDER_MODE_STREAMING
 ******************************************************************************/
#define TRC_CFG_RECORDER_MODE TRC_RECORDER_MODE_STREAMING

/******************************************************************************
 * TRC_CFG_FREERTOS_VERSION
 *
 * Specify what version of FreeRTOS that is used (don't change unless using the
 * trace recorder library with an older version of FreeRTOS).
 *
 * TRC_FREERTOS_VERSION_7_3						If using FreeRTOS v7.3.x
 * TRC_FREERTOS_VERSION_7_4						If using FreeRTOS v7.4.x 
 * TRC_FREERTOS_VERSION_7_5_OR_7_6				If using FreeRTOS v7.5.0 - v7.6.0
 * TRC_FREERTOS_VERSION_8_X						If using FreeRTOS v8.X.X
 * TRC_FREERTOS_VERSION_9_0_0					If using FreeRTOS v9.0.0
 * TRC_FREERTOS_VERSION_9_0_1					If using FreeRTOS v9.0.1
 * TRC_FREERTOS_VERSION_9_0_2					If using FreeRTOS v9.0.2
 * TRC_FREERTOS_VERSION_10_0_0					If using FreeRTOS v10.0.0 or later
 *****************************************************************************/
#define TRC_CFG_FREERTOS_VERSION TRC_FREERTOS_VERSION_10_0_0
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

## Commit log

2019-07-10 Minor Bugfixes
    Minor fixes to do with control loop.
    PWM freq upped to 2khz but still at 500hz refresh rate.
    [IMU.c, STM32_FLIGHT_CONTROLLER.ioc, main.c]
2019-07-19 Working PID control at 505hz
    Working PID control at 505hz, gains need tuning
2019-07-26 Added NRF24 module libs
    Added NRF24 module libs and implemented basic Rx functionality receiving from STM32F7 board
2019-08-01 TIM3 Reconfigured for DMA UART Timeout detection
2019-08-08 Working throttle control
2019-08-09 Added ADC for battery level
2019-09-08 DMP but with yaw drift
    [main.c]
2019-09-09 Added Eagle project files
    [Flight_Controller_board.brd, Flight_Controller_board.sch, HR04_board.brd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]
2019-09-13 I2C replaced with non blocking DMA
    [IMU.c, STM32_FLIGHT_CONTROLLER.ioc, main.c]
2019-09-22 GPS parsing redone
    Using UART Idle line detection interrupt to self time out without using timer like before (Note: have to copy over again HAL_UART.c and .h files if cubeMX is regenerated as have implemented a small h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
2019-09-23 Fixed NRF24 connection with RTOS
    [MY_NRF24.c, STM32_FLIGHT_CONTROLLER.ioc, main.c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]
2019-09-24 re calibrated mag
2019-09-25 fixed yaw ctrl
2019-10-16 PID values received externally from Tx
2019-10-29 Fixed NRF Tx/Rx Delay
    [IMU.c, MY_NRF24.c, RF_Comms.c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]
2019-10-29 I2C with IT

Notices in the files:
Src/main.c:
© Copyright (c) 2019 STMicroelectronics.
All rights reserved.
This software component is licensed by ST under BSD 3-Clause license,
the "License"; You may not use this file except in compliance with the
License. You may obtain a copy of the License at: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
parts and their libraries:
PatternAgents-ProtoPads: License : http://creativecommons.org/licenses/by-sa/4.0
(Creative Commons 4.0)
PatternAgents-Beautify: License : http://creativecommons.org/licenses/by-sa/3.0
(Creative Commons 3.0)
